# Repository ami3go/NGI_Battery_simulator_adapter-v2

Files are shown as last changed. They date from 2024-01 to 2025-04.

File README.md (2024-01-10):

# NGI_Battery_simulator_adapter-v2
 Simple PCB adapter for easy wiring from sell cimulator to load

 Features: 
 - Power wirse +  sensign wires
 - Optional NTC emulation
 - 3.5 mm universal connector
 - Additioan connector for extnal measurement device
 - cable ties holes to fix bulky wires

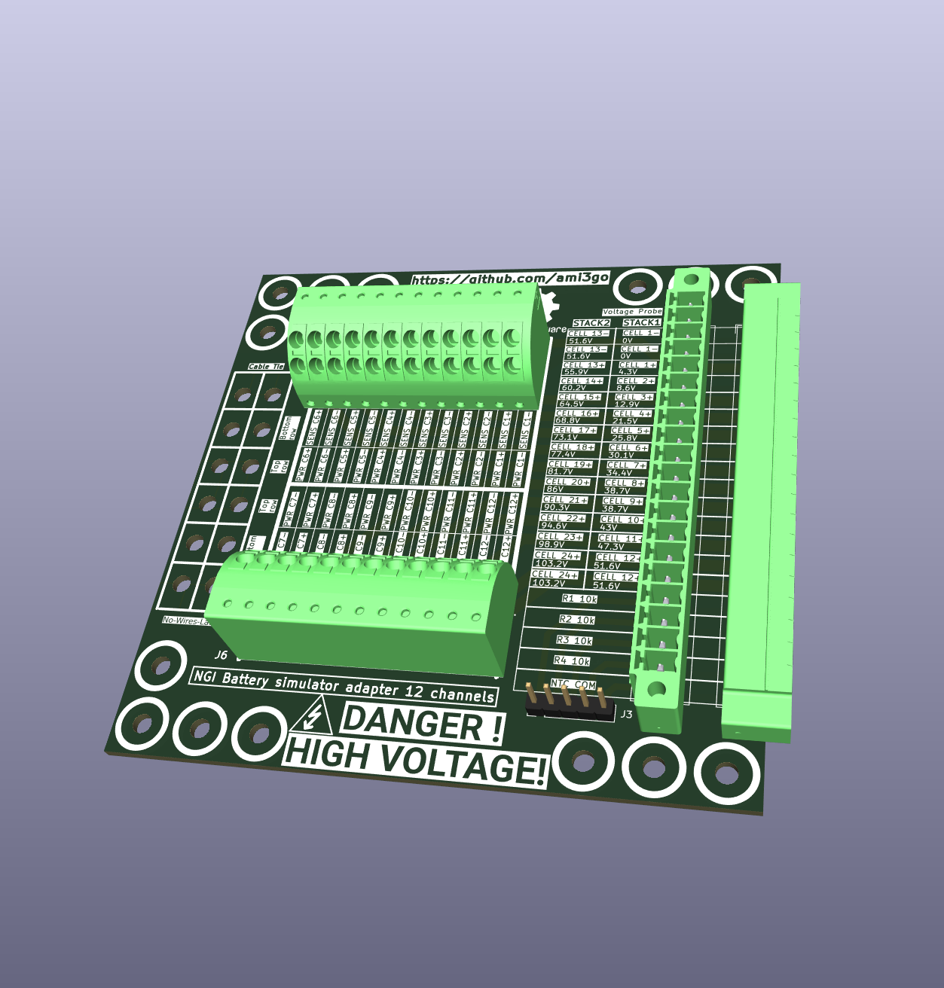
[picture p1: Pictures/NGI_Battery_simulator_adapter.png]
Rander picture


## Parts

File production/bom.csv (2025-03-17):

Designator | Footprint | Quantity | Value | LCSC Part #
H1, H10, H11, H12, H13, H14, H15, H16, H17, H18, H2, H3, H4, H5_3, H5_2, H5, H6, H7_2, H7, H8_6, H8_5, H8_4, H8_3, H8_2, H8, H9 | MountingHole_3.2mm_M3_ISO14580 | 26 | MountingHole
J1 | TerminalBlock_4Ucon_1x20_P3.50mm_Vertical_copy | 1 | Screw_Terminal_01x20
J2, J6 | 1725042 | 2 | 1725042
J3 | PinHeader_1x05_P2.54mm_Vertical | 1 | Conn_01x05
J4 | TerminalBlock_4Ucon_1x20_P3.50mm_horisontal | 1 | Screw_Terminal_01x20 | 1843978
R1, R2, R3, R4, R5, R6, R7, R8 | R_0603 | 8 | 10k_0603_0.1%

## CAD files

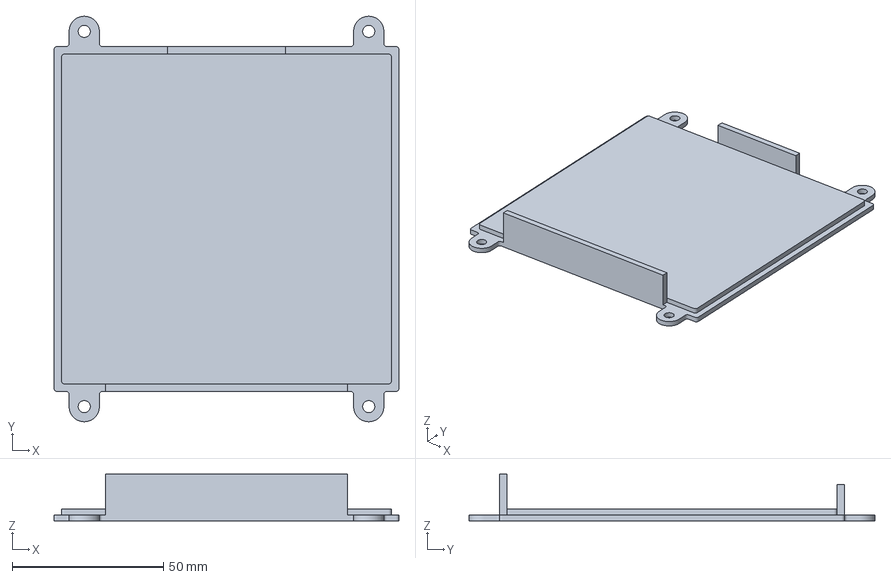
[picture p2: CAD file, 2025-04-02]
3D_Enclosure/Case_2.1-PartBody.3mf
114.0 x 134.0 x 15.5 mm

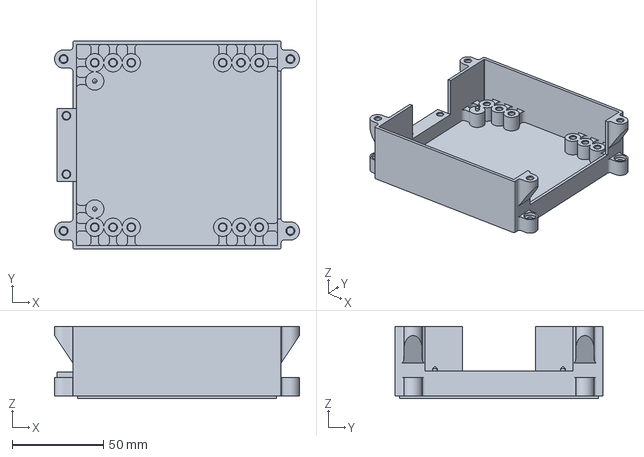
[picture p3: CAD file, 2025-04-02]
3D_Enclosure/Case_1.3.5-Bottom_cover.3mf
134.0 x 114.0 x 39.5 mm

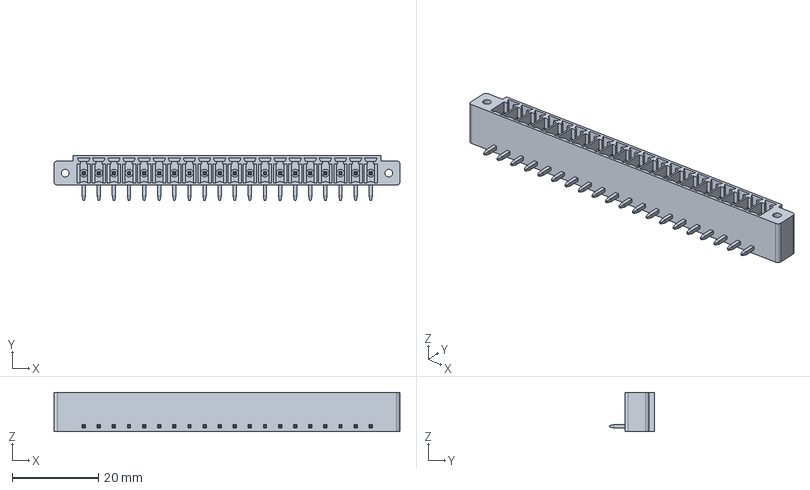
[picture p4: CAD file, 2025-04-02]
3D_Enclosure/Connector.FCStd
80.3 x 10.4 x 9.14 mm

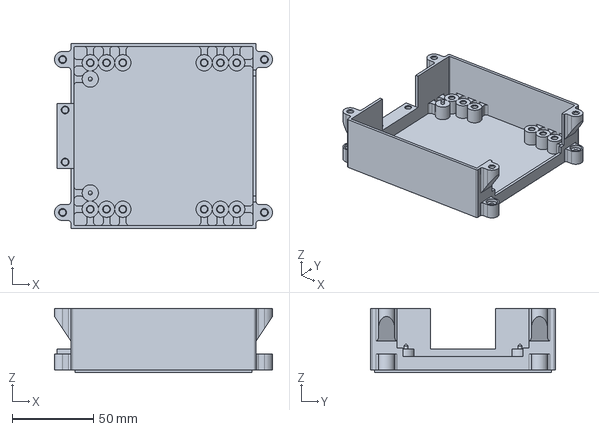
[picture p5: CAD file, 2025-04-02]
3D_Enclosure/Case_1.3.5.FCStd
134.0 x 114.0 x 39.5 mm

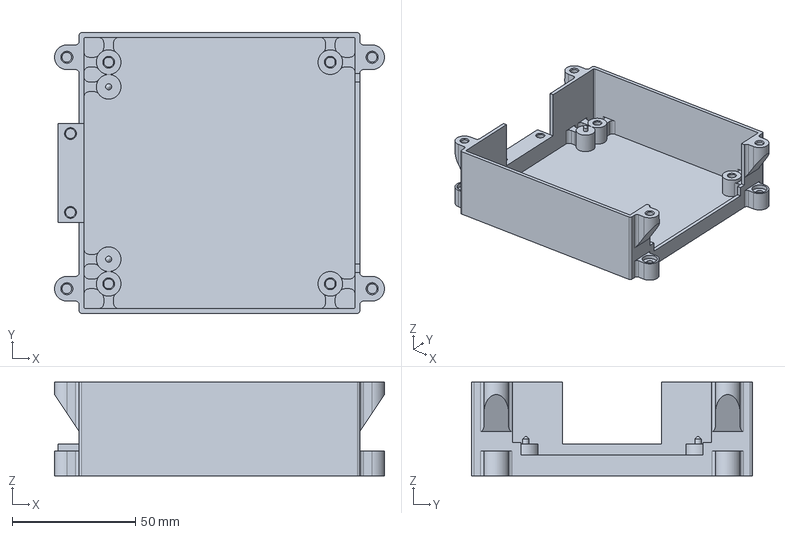
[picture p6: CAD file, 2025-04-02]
3D_Enclosure/Case_1.4.FCStd
134.0 x 114.0 x 38.0 mm

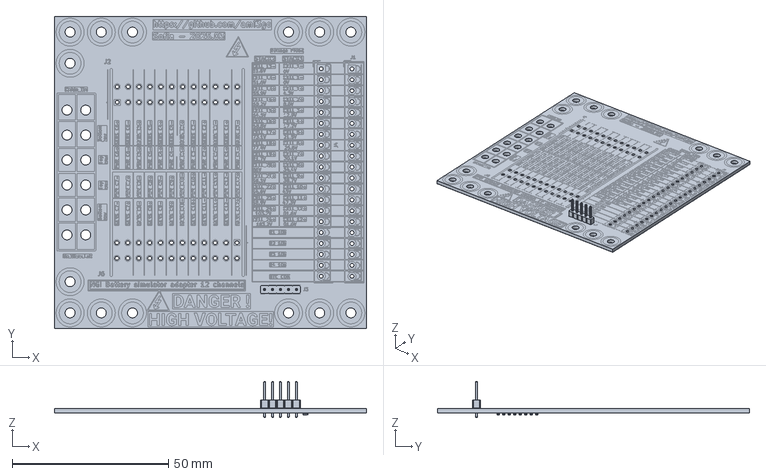
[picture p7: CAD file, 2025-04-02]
3D_Enclosure/PCB.FCStd
100.0 x 100.0 x 11.5 mm

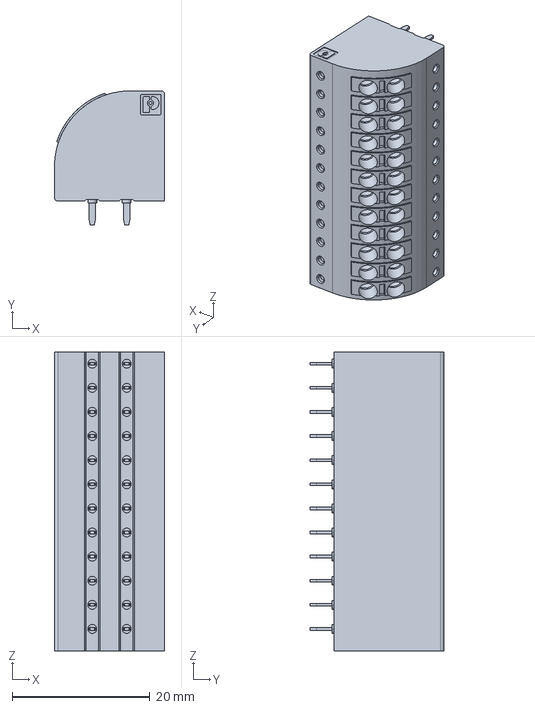
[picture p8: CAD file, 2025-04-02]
3D_Enclosure/Connector2.FCStd
16.0 x 19.5 x 43.4 mm

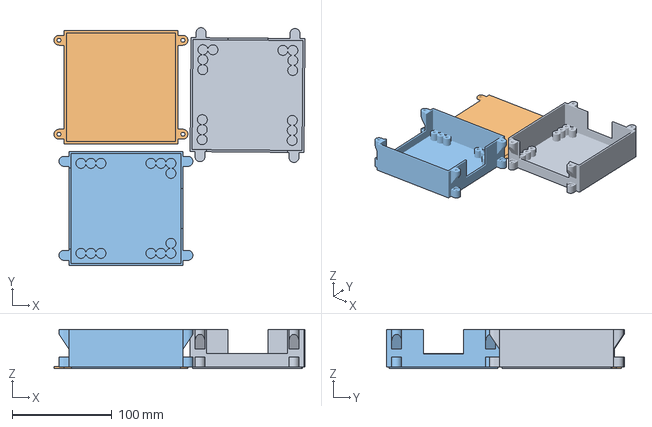
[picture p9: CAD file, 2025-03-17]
3D_Enclosure/Case_1.1-Bottom_cover_v1.3mf
251.0 x 237.7 x 39.5 mm

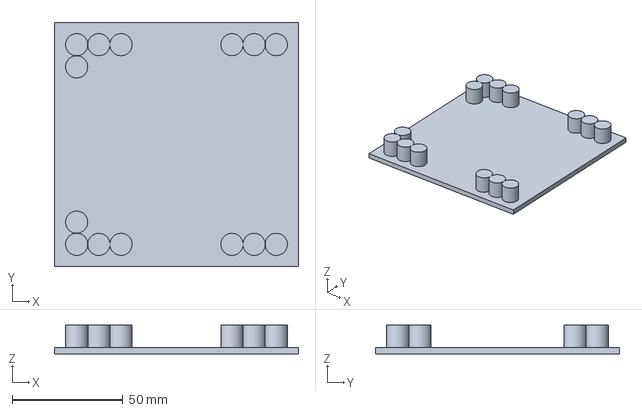
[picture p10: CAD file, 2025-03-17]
3D_Enclosure/Case_1.FCStd
110.0 x 110.0 x 13.0 mm

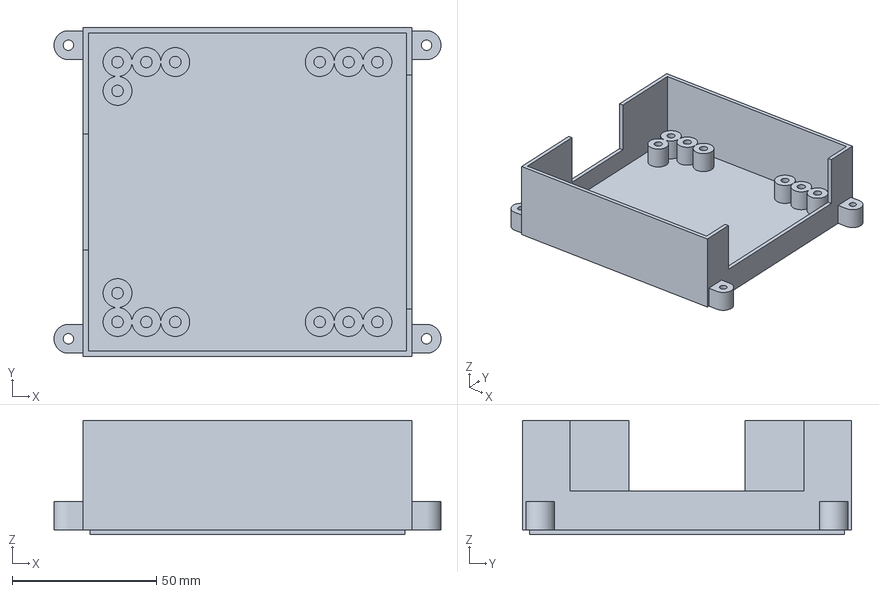
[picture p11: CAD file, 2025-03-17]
3D_Enclosure/Case_1.1-Bottom_cover.3mf
134.0 x 114.0 x 39.5 mm

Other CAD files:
3D_Enclosure/Assembly_v4.FCStd
3D_Enclosure/Assemsbly_V2.FCStd
3D_Enclosure/Case_2.1.FCStd
3D_Enclosure/Case_1.3.FCStd
3D_Enclosure/Case_1.1.FCStd
3D_Enclosure/Case_1.2.FCStd
3D_Enclosure/39506-1020.stp
3D_Enclosure/1725042.stp
3D_Enclosure/Archive/Assemsbly_V2.FCStd
3D_Enclosure/Archive/Case_1.1.FCStd
3D_Enclosure/Archive/Case_1.2.FCStd
3D_Enclosure/Archive/Case_1.3.FCStd
3D_Enclosure/Archive/assembly.FCStd
3D_Enclosure/assembly.FCStd

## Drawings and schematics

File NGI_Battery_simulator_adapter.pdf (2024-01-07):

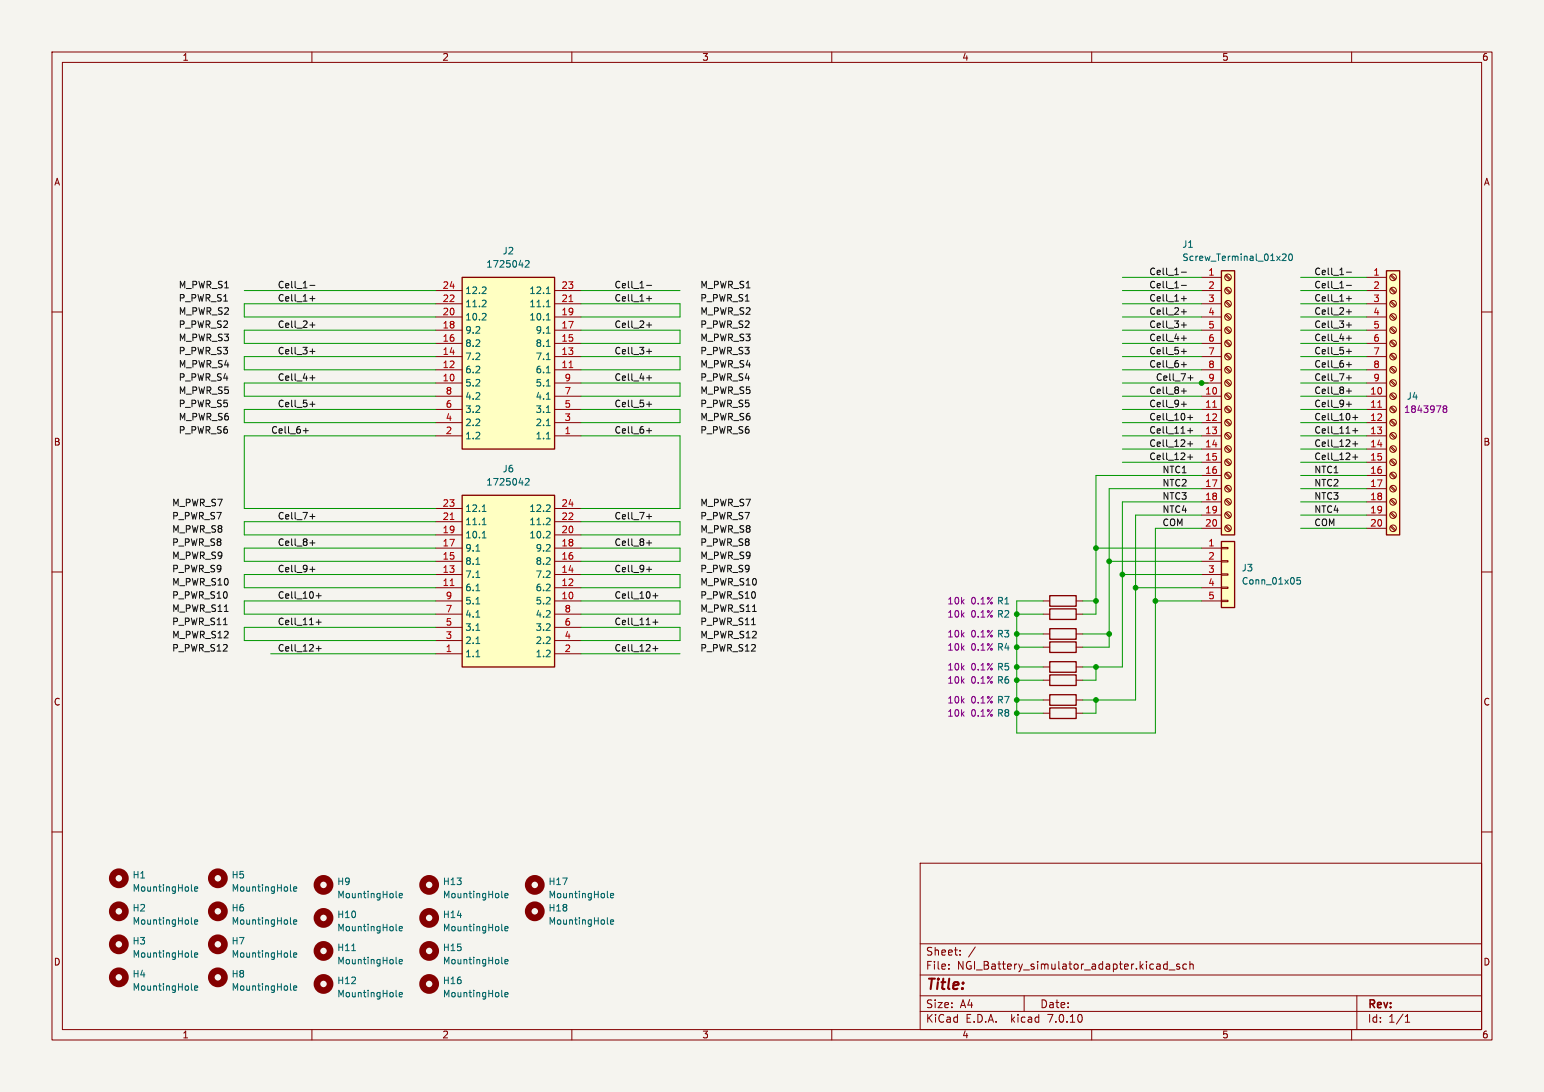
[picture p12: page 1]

10k 0.1% R8 H3 MountingHole H1 MountingHole H2 MountingHole H4 MountingHole

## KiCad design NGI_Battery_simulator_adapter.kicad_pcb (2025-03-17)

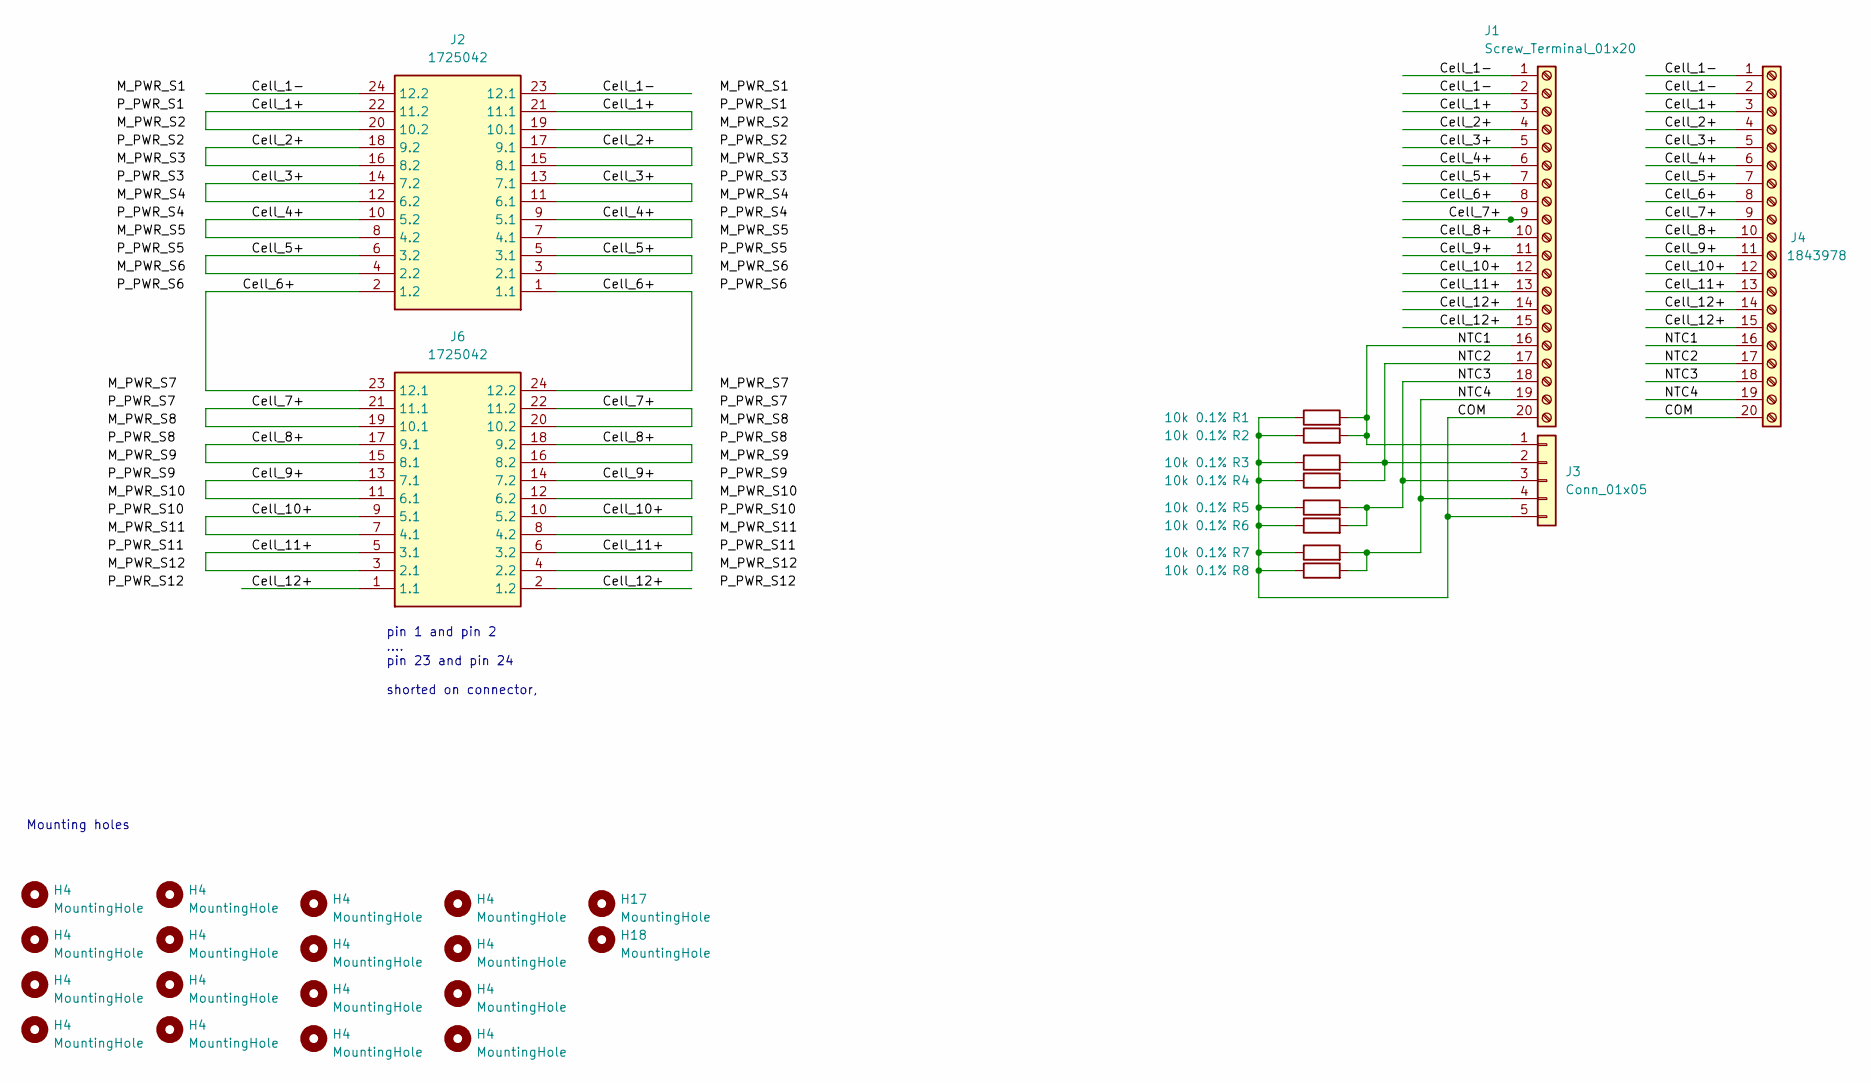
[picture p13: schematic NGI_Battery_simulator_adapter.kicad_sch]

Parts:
H4, H17, H18: MountingHole; MountingHole_3.2mm_M3_ISO14580
J1: Screw_Terminal_01x20; TerminalBlock_4Ucon_1x20_P3.50mm_Vertical_copy
J2, J6: 1725042; Manufacturer_Part_Number 1725042; Mouser Part Number 651-1725042
J3: Conn_01x05; PinHeader_1x05_P2.54mm_Vertical
J4: Screw_Terminal_01x20; TerminalBlock_4Ucon_1x20_P3.50mm_horisontal; MPN 1843978
R1, R2, R3, R4, R5, R6, R7, R8: 10k_0603_0.1%; R_0603; Part Number ERJ-PB3B1002V

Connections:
/COM: J1.20, J3.5, J4.20, R1.1, R2.1, R3.1, R4.1, R5.1, R6.1, R7.1, R8.1
/Cell_1+: J1.3, J2.19 (10.1), J2.20 (10.2), J2.21 (11.1), J2.22 (11.2), J4.3
/Cell_1-: J1.1, J1.2, J2.23 (12.1), J2.24 (12.2), J4.1, J4.2
/Cell_2+: J1.4, J2.15 (8.1), J2.16 (8.2), J2.17 (9.1), J2.18 (9.2), J4.4
/Cell_3+: J1.5, J2.11 (6.1), J2.12 (6.2), J2.13 (7.1), J2.14 (7.2), J4.5
/Cell_4+: J1.6, J2.7 (4.1), J2.8 (4.2), J2.9 (5.1), J2.10 (5.2), J4.6
/Cell_5+: J1.7, J2.3 (2.1), J2.4 (2.2), J2.5 (3.1), J2.6 (3.2), J4.7
/Cell_6+: J1.8, J2.1 (1.1), J2.2 (1.2), J4.8, J6.23 (12.1), J6.24 (12.2)
/Cell_7+: J1.9, J4.9, J6.19 (10.1), J6.20 (10.2), J6.21 (11.1), J6.22 (11.2)
/Cell_8+: J1.10, J4.10, J6.15 (8.1), J6.16 (8.2), J6.17 (9.1), J6.18 (9.2)
/Cell_9+: J1.11, J4.11, J6.11 (6.1), J6.12 (6.2), J6.13 (7.1), J6.14 (7.2)
/Cell_10+: J1.12, J4.12, J6.7 (4.1), J6.8 (4.2), J6.9 (5.1), J6.10 (5.2)
/Cell_11+: J1.13, J4.13, J6.3 (2.1), J6.4 (2.2), J6.5 (3.1), J6.6 (3.2)
/Cell_12+: J1.14, J1.15, J4.14, J4.15, J6.1 (1.1), J6.2 (1.2)
/NTC1: J1.16, J3.1, J4.16, R1.2, R2.2
/NTC2: J1.17, J3.2, J4.17, R3.2, R4.2
/NTC3: J1.18, J3.3, J4.18, R5.2, R6.2
/NTC4: J1.19, J3.4, J4.19, R7.2, R8.2

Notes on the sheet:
Mounting holes
pin 1 and pin 2 .... pin 23 and pin 24 shorted on connector,

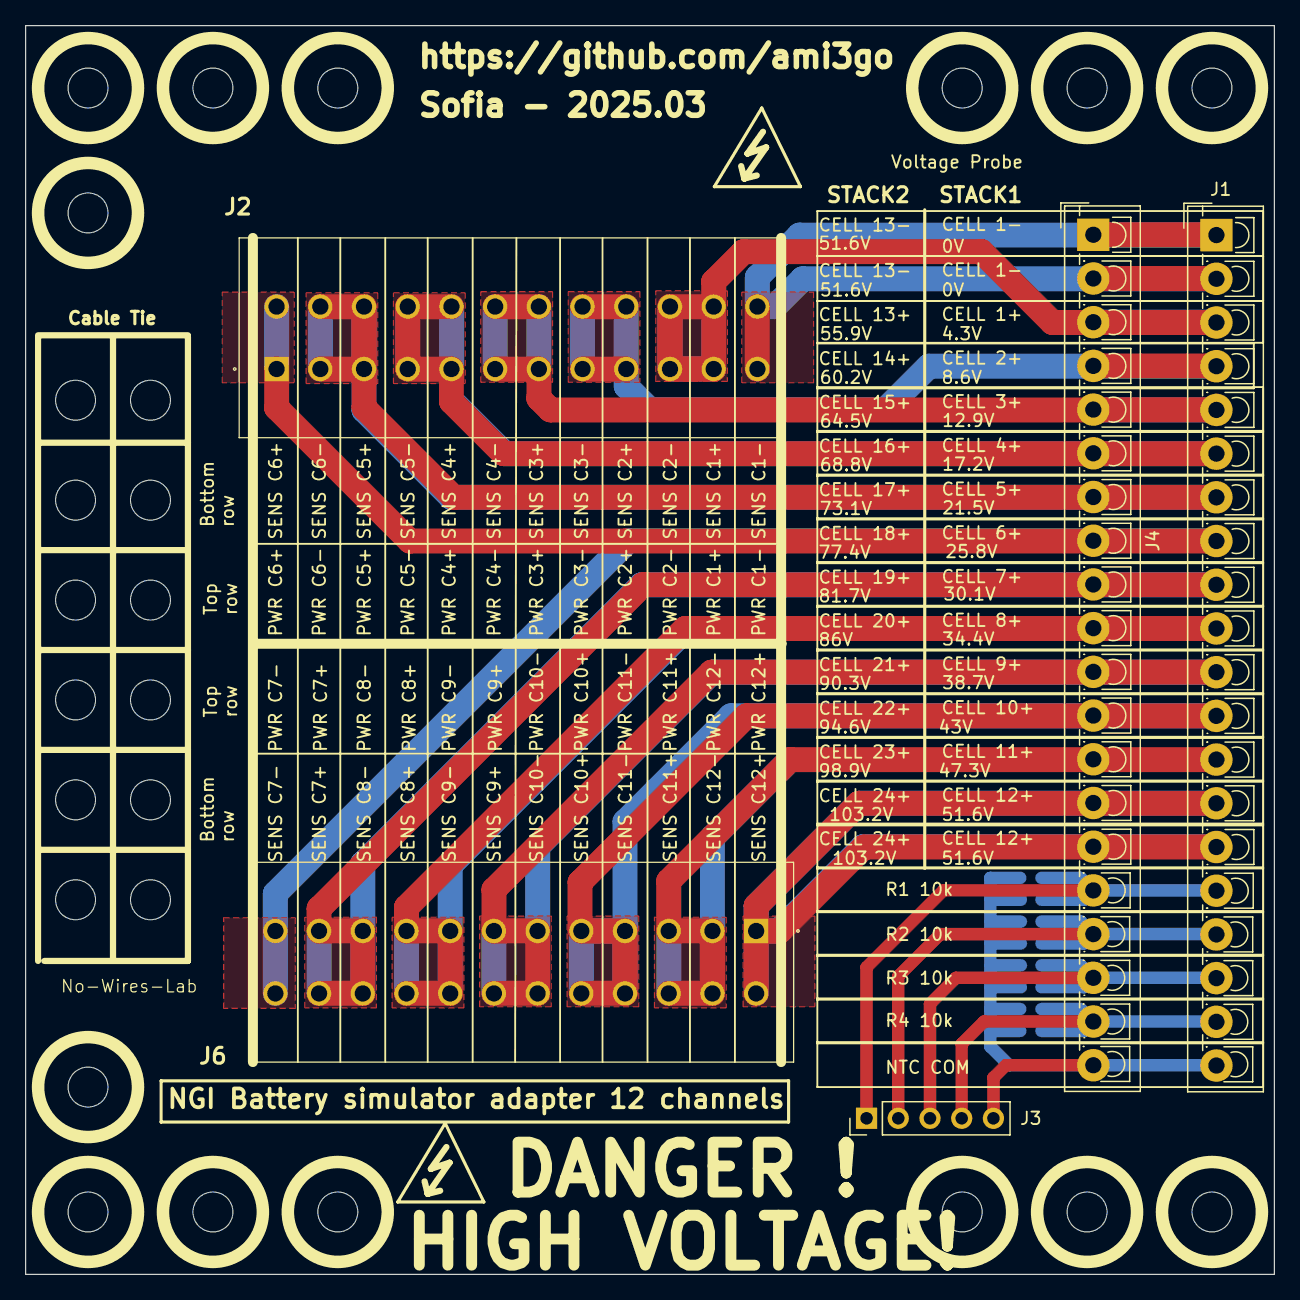
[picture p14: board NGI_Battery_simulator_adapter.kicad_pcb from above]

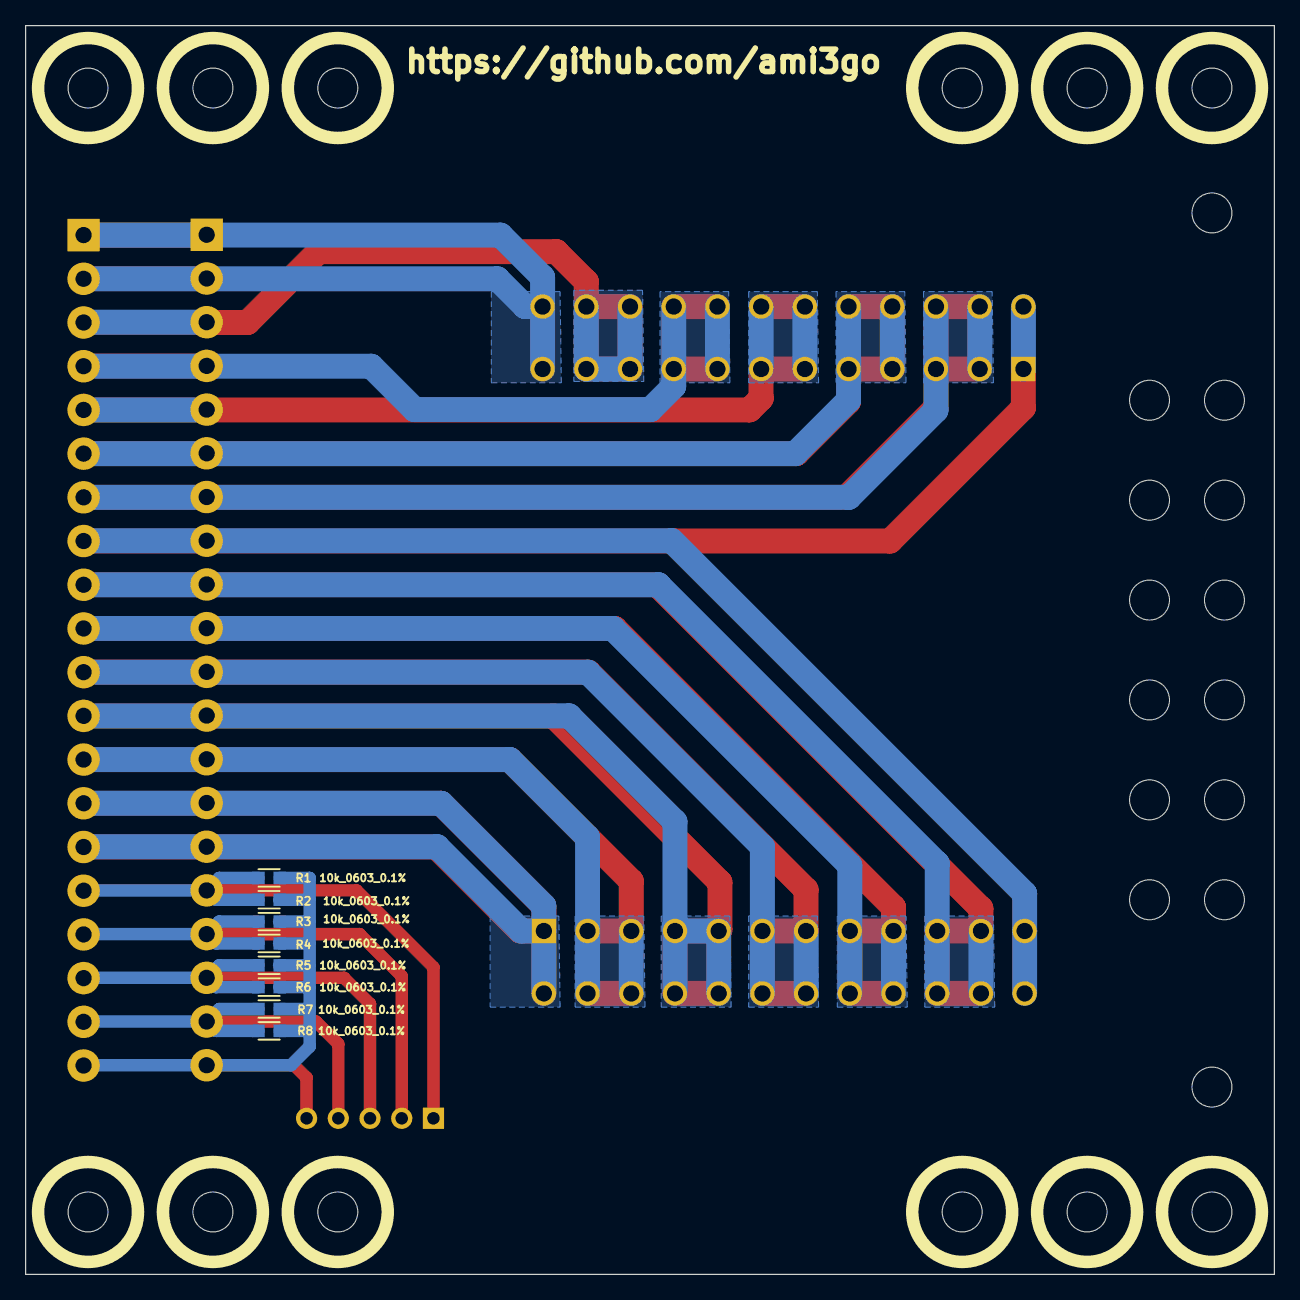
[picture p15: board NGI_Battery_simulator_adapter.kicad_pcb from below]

Board: 2 copper layers, 100.0 x 100.0 mm, 39 parts (8 on the bottom side), 18 nets.

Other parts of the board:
H1, H2, H3, H5, H5#2, H5#3, H6, H7, H7#2, H8, H8#2, H8#3, H8#4, H8#5, H8#6, H9, H10, H11, H12, H13, H14, H15, H16: MountingHole; MountingHole_3.2mm_M3_ISO14580

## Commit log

2024-01-08 gerber update
    fix some DRC error, minor change
    [NGI_Battery_simulator_adapter.kicad_pcb, NGI_Battery_simulator_adapter.kicad_sch, bom.csv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]
2025-03-17 update for Kicad 9
    [NGI_Battery_simulator_adapter.kicad_pcb]
2025-03-17 Update gerbers
    [bom.csv, designators.csv, positions.csv]
2025-03-17 Add 3D
    [Case_1.1-Bottom_cover.3mf, Case_1.1-Bottom_cover_v1.3mf, Case_1.1.FCStd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]
2025-03-19 Updated 3D
    [Assemsbly_V2.FCStd, Case_1.3.5.FCStd, Case_2.1.FCStd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]
2025-04-02 3D enclosure work in progress
    [1725042.stp, 39506-1020.stp, Assembly_v4.FCStd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]
